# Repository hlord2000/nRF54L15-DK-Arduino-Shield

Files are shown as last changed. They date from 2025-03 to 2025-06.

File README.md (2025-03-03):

# nRF54L15-DK to Arduino Shield Adapter

This adapter board allows you to connect Arduino shields to your nRF54L15-DK development kit for basic prototyping needs.

<div align="center">
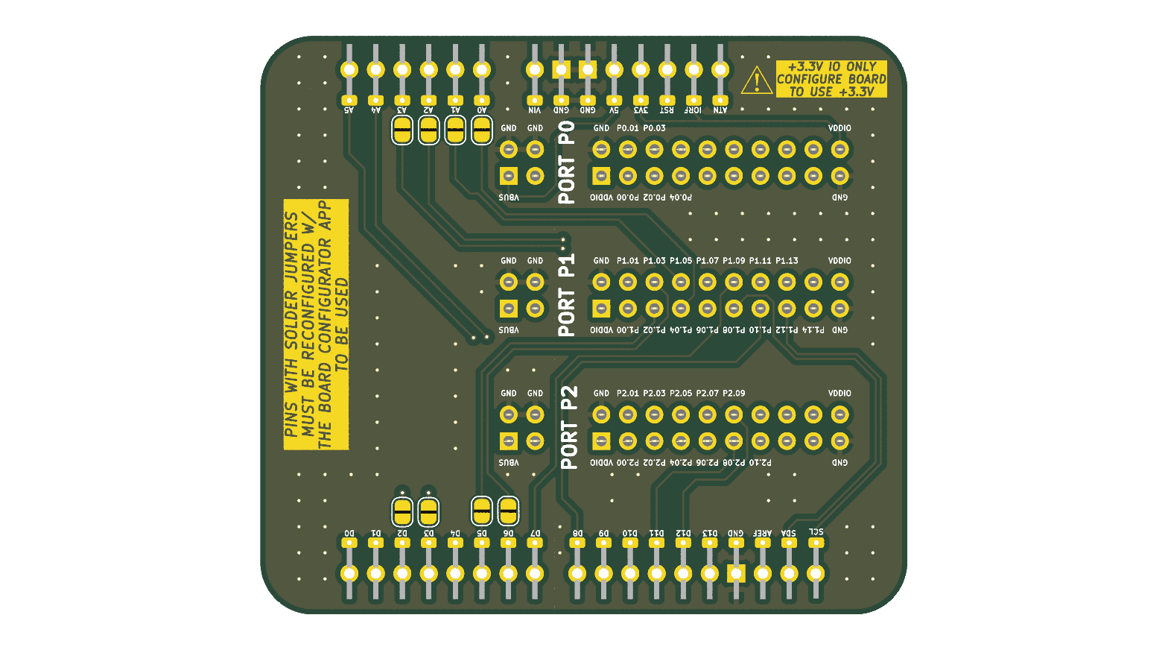
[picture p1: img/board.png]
nRF54L15-DK Arduino Shield Adapter - Top View
  
</div>

## Features

- Compatible with nRF54L15-DK development kit
- Standard Arduino shield form factor
- Solder jumpers for pin configuration flexibility

## ⚠️ Important Usage Notes

- **3.3V OPERATION ONLY** - Configure your nRF54L15-DK to use +3.3V logic
- Pins with solder jumpers are **NOT CONNECTED BY DEFAULT**
- **PINS WITH SOLDER JUMPERS MUST BE RECONFIGURED WITH THE BOARD CONFIGURATOR APP TO BE USED**

<div align="center">
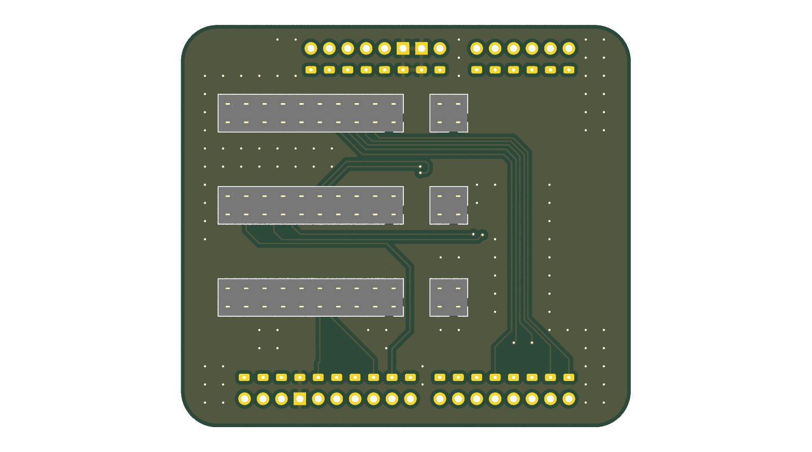
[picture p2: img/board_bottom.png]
nRF54L15-DK Arduino Shield Adapter - Bottom View
  
</div>

## Getting Started

1. Ensure your nRF54L15-DK is configured for 3.3V operation
2. Attach this adapter board to your nRF54L15-DK
3. For pins with solder jumpers:
   - Keep jumpers open for default configuration
   - If needed, close jumpers and reconfigure pins using the Board Configurator App

## Compatibility

This adapter is designed for basic Arduino shields that operate at 3.3V logic levels. Shields requiring 5V logic are not supported without additional level shifting.

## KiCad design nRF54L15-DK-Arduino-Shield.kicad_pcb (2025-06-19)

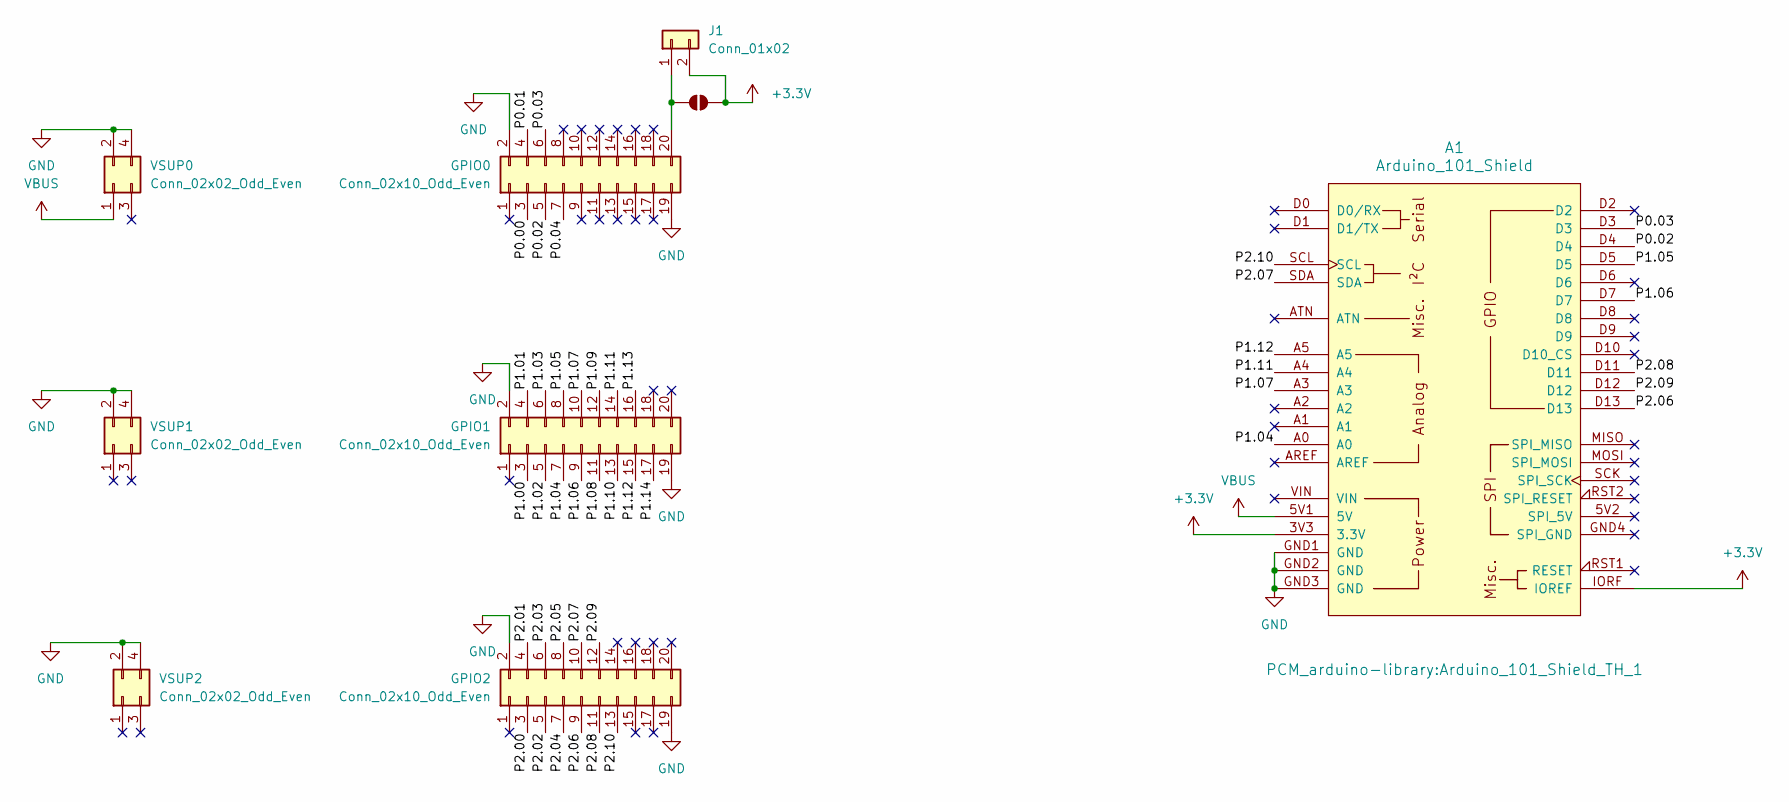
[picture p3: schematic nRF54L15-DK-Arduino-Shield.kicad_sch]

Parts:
A1: Arduino_101_Shield; Arduino_101_Shield_TH_1
GPIO0, GPIO1, GPIO2: Conn_02x10_Odd_Even; PinSocket_2x10_P2.54mm_Vertical
J1: Conn_01x02; PinHeader_1x02_P2.54mm_Vertical
JP1: SolderJumper_2_Open; SolderJumper-2_P1.3mm_Open_RoundedPad1.0x1.5mm
VSUP0, VSUP1, VSUP2: Conn_02x02_Odd_Even; PinSocket_2x02_P2.54mm_Vertical

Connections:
+3.3V: A1.3V3 (3.3V), A1.IORF (IOREF), J1.2, JP1.2 (B)
/P0.00: GPIO0.3
/P0.01: GPIO0.4
/P0.02: A1.D4, GPIO0.5
/P0.03: A1.D3, GPIO0.6
/P0.04: GPIO0.7
/P1.00: GPIO1.3
/P1.01: GPIO1.4
/P1.02: GPIO1.5
/P1.03: GPIO1.6
/P1.04: A1.A0, GPIO1.7
/P1.05: A1.D5, GPIO1.8
/P1.06: A1.D7, GPIO1.9
/P1.07: A1.A3, GPIO1.10
/P1.08: GPIO1.11
/P1.09: GPIO1.12
/P1.10: GPIO1.13
/P1.11: A1.A4, GPIO1.14
/P1.12: A1.A5, GPIO1.15
/P1.13: GPIO1.16
/P1.14: GPIO1.17
/P2.00: GPIO2.3
/P2.01: GPIO2.4
/P2.02: GPIO2.5
/P2.03: GPIO2.6
/P2.04: GPIO2.7
/P2.05: GPIO2.8
/P2.06: A1.D13, GPIO2.9
/P2.07: A1.SDA, GPIO2.10
/P2.08: A1.D11, GPIO2.11
/P2.09: A1.D12, GPIO2.12
/P2.10: A1.SCL, GPIO2.13
GND: A1.GND1 (GND), A1.GND2 (GND), A1.GND3 (GND), GPIO0.2, GPIO0.19, GPIO1.2, GPIO1.19, GPIO2.2, GPIO2.19, VSUP0.2, VSUP0.4, VSUP1.2, VSUP1.4, VSUP2.2, VSUP2.4
unnamed: GPIO0.20, J1.1, JP1.1 (A)
VBUS: A1.5V1 (5V), VSUP0.1

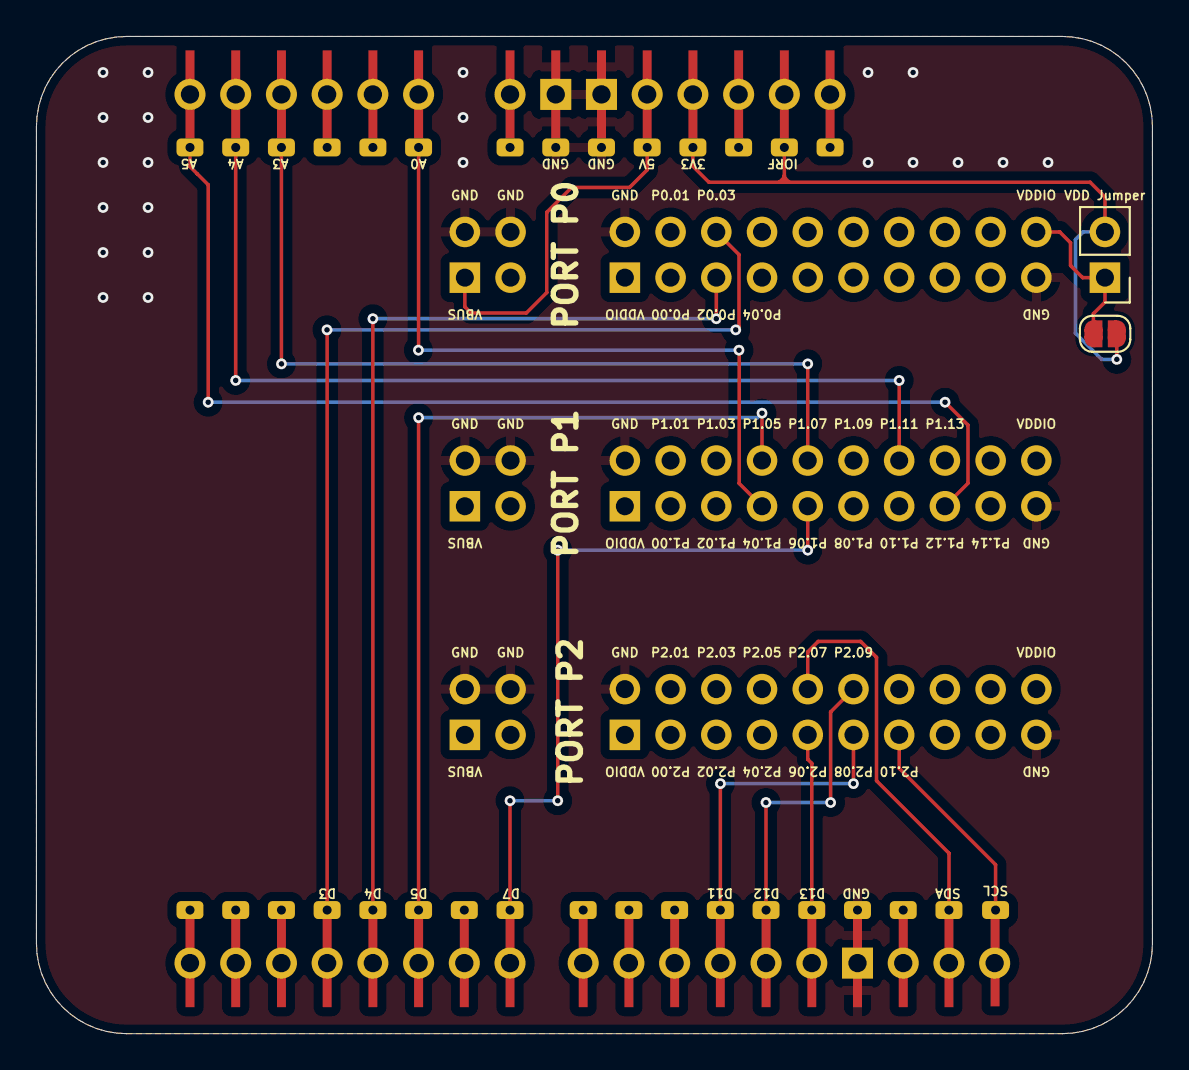
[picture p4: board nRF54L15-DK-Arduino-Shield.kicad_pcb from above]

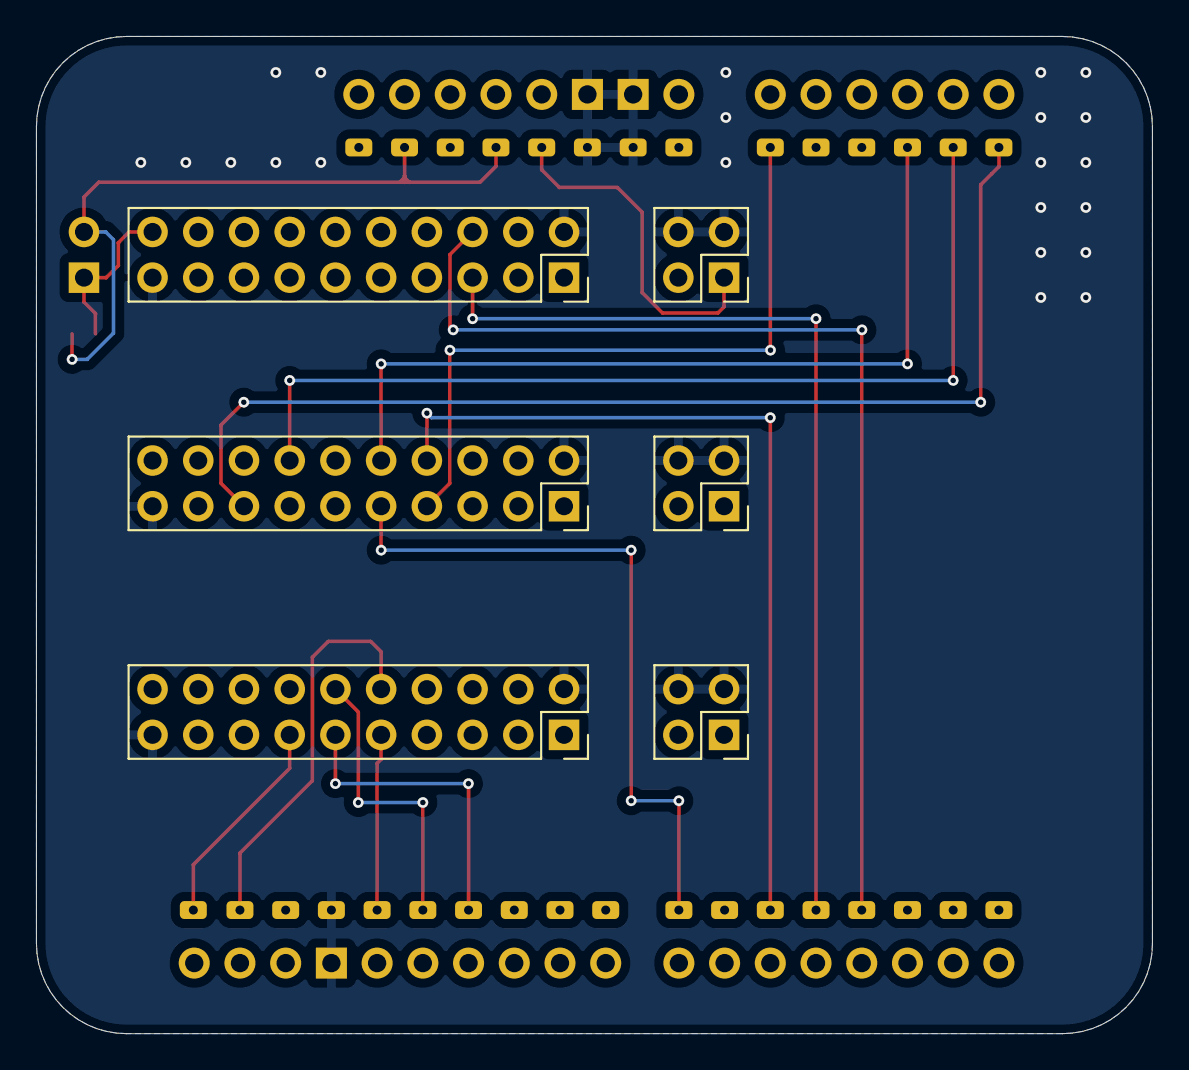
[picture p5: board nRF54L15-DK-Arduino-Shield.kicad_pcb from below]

Board: 2 copper layers, 62.0 x 55.4 mm, 9 parts (6 on the bottom side), 17 nets.

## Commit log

2025-03-03 Initial commit.
    [nRF54L15-DK-Arduino-Shield-B_Cu.gbl, nRF54L15-DK-Arduino-Shield-B_Mask.gbs, nRF54L15-DK-Arduino-Shield-B_Paste.gbp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]
2025-03-21 Updates for LR1110 Arduino shield
    [nRF54L15-DK-Arduino-Shield-B_Cu.gbl, nRF54L15-DK-Arduino-Shield-B_Mask.gbs, nRF54L15-DK-Arduino-Shield-B_Paste.gbp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]
2025-06-19 Added VDD jumper
    [nRF54L15-DK-Arduino-Shield-B_Cu.gbl, nRF54L15-DK-Arduino-Shield-B_Mask.gbs, nRF54L15-DK-Arduino-Shield-B_Paste.gbp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]
